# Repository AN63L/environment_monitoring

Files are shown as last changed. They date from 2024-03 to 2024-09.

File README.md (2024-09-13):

# Environment monitoring system and simple web server
Budget friendly and lower-power consumption environment monitoring system with ESP32 board, BME680 sensor and PM-G7.

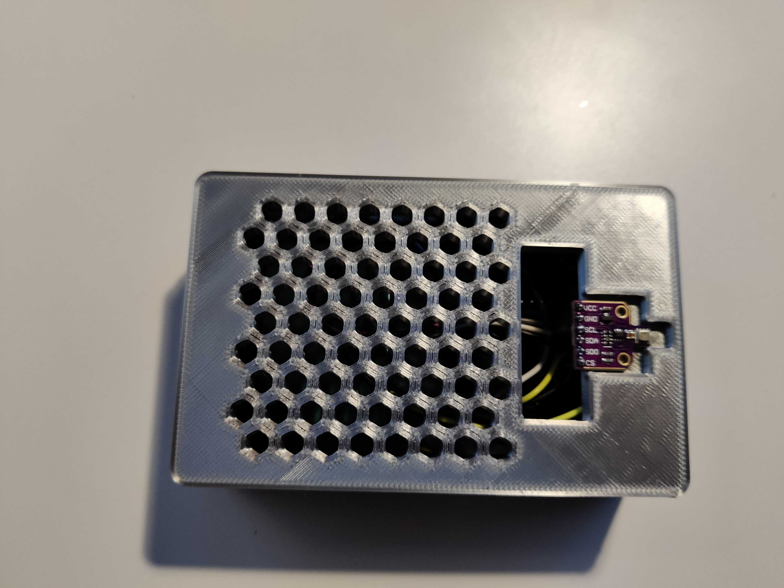
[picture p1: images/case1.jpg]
Case view

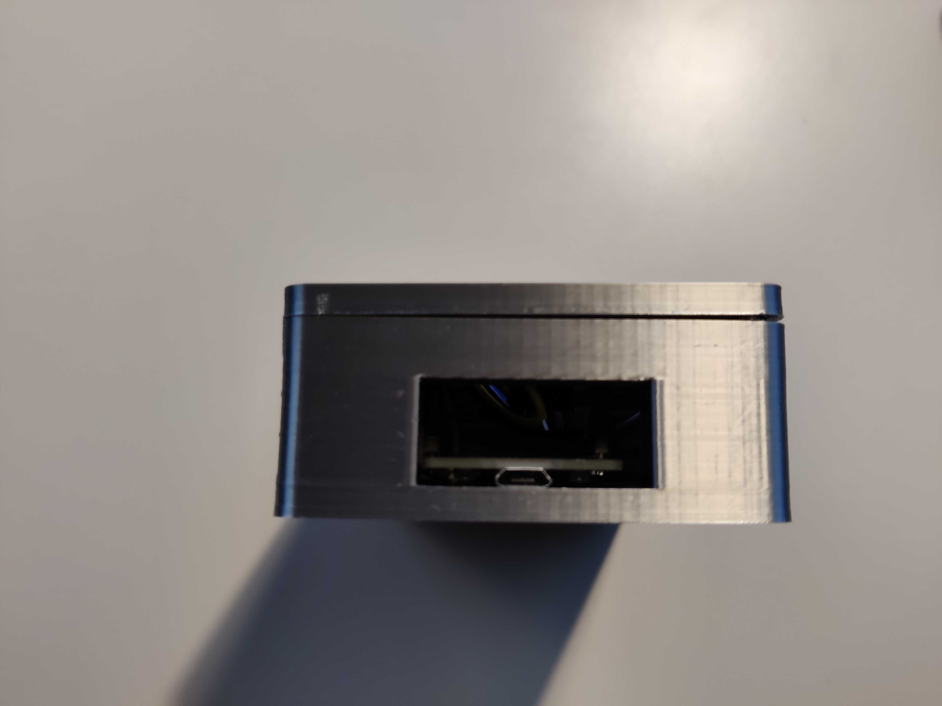
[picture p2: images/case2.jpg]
Case view

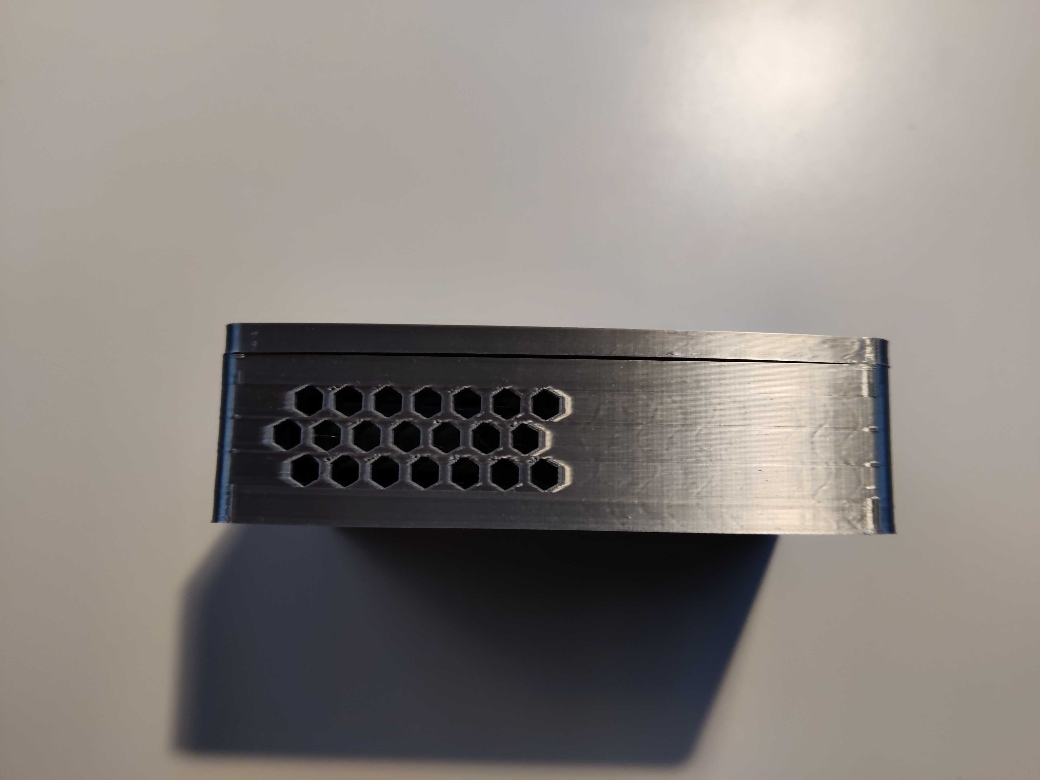
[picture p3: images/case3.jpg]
Case view

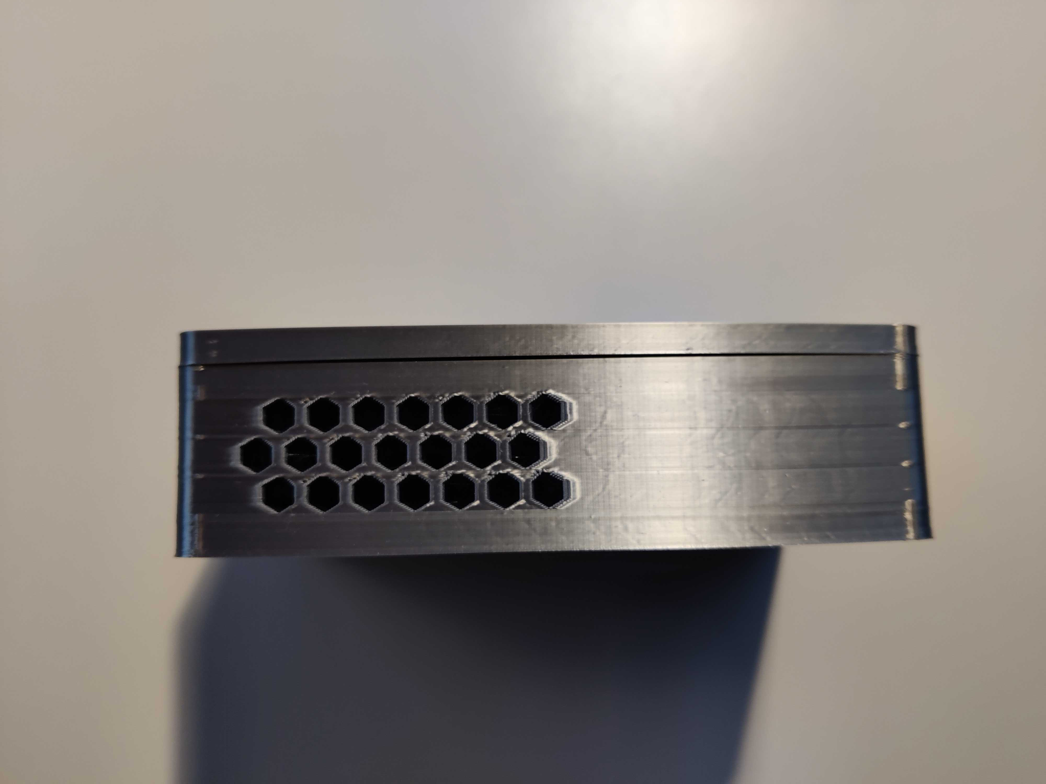
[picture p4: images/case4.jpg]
Case view


## Overview

This guide is part of a project I built to monitor the air quality, temperature, humidity, pressure and gas in a closed room. 

It's built using an ESP32 board for its low power consumption and small size. 

I've paired this project with a notification system (only for HA), you can configure different notifications based on my needs. It's placed in a room and notifies me when: 
- The air quality has deteriorated and I need to open a window to refresh the air
- The temperature is running high and I need to cool down with a fan
- The temperature is running low and I need to turn up the heaters
- The air quality is dangerous because of different levels of gas
- The air quality based on the PMS sensor data

I've also 3D printed a small case (PLA) to hold the pieces together.

Excluding time for build and development, the breakdown of the costs are as follows: 

- EUR 7.66 for the ESP32
- EUR 18.50 for the BME680 sensor
- EUR 19.99 for the PMS7003 sensor
- EUR 1.95 PMS7003 sensor adapter
- EUR 0.67 for the 8 magnets
- EUR 5 for the power supply (I used a micro-USB power supply I had already, I'm guessing you can get one for that price off Amazon)
- EUR 20 for the soldering iron
- EUR 0.69 for the 69 grams of PLA (approx)
- 
The total of this project comes down to round **EUR 80**.

I used platformIO to manage the ESP32, the main folder with the content is available in the folder "ESP32 ENVIRONMENT MONITORING SYSTEM"

## Resources

- [ESP32 board by diymore ](https://www.amazon.fr/dp/B0BS6R68H6?psc=1&ref=ppx_yo2ov_dt_b_product_details)
- [BME680 sensor](https://www.amazon.fr/dp/B07K1CGQTJ?psc=1&ref=ppx_yo2ov_dt_b_product_details)
- [PM-G7 / PMSA7003 sensor](https://www.amazon.fr/dp/B0B1526JHQ?psc=1&ref=ppx_yo2ov_dt_b_product_details)
- [PMS7003 sensor adapter](https://soldered.com/product/pms7003-sensor-adapter/)
- 8 Jumper cables (female to female)
- PLA + (I have a personal preference for SUNLU PLA +, but you can use any kind of PLA)
- [5x3mm magnets for the case](https://www.amazon.fr/dp/B0C9WQYZ27?ref=ppx_yo2ov_dt_b_product_details&th=1)
- A soldering iron and relevant materials
- Superglue to glue the BME680 sensor to the case

## 3D prints

The parts were printed using a Creality CR-20 pro. 

The pieces are as follows: 
- Lid (v3) 
- Case (v2) (or case_soldered)

The original version of the case had some issues: 
- there was not enough space to attach the jumper cables to the BME680 sensor
- the stands for the ESP32 were way too far (the reference model I used was incorrect) and the stand weren't solid enough
- the whole for the charging port of the ESP32 was a little too low
- the depth of the magnets could be improved by 1mm to avoid any space between the lid and the case

Overall it should work if you print it but you'll need to find a way to connect the BME680 sensor, remove the stands. You could glue everything together with hot glue to avoid any issues with the charging port of the ESP32. 

I wanted to improve the design in general and fix the above issues, you'll find the second version of the case is much better overall. 

There are three versions of the lid. For some reason, I could not print the first version with the hex holes, so I created the second version which should provide a lot more air to the sensors but is less beautiful and is not suitable for exterior use. 

The third version is cleaned up to fit my needs with enough air, with a better design, rounded corners and a thinner format.

The print times totals to 8h and 34 minutes. 

*If you are using the soldered adapter* I made improvements to the case, as the previous versions didn't leave enough space for the jumper cables (see image below). I took the opportunity to remove the space for the PMS7003 which wasn't fit for purpose (see comment above).

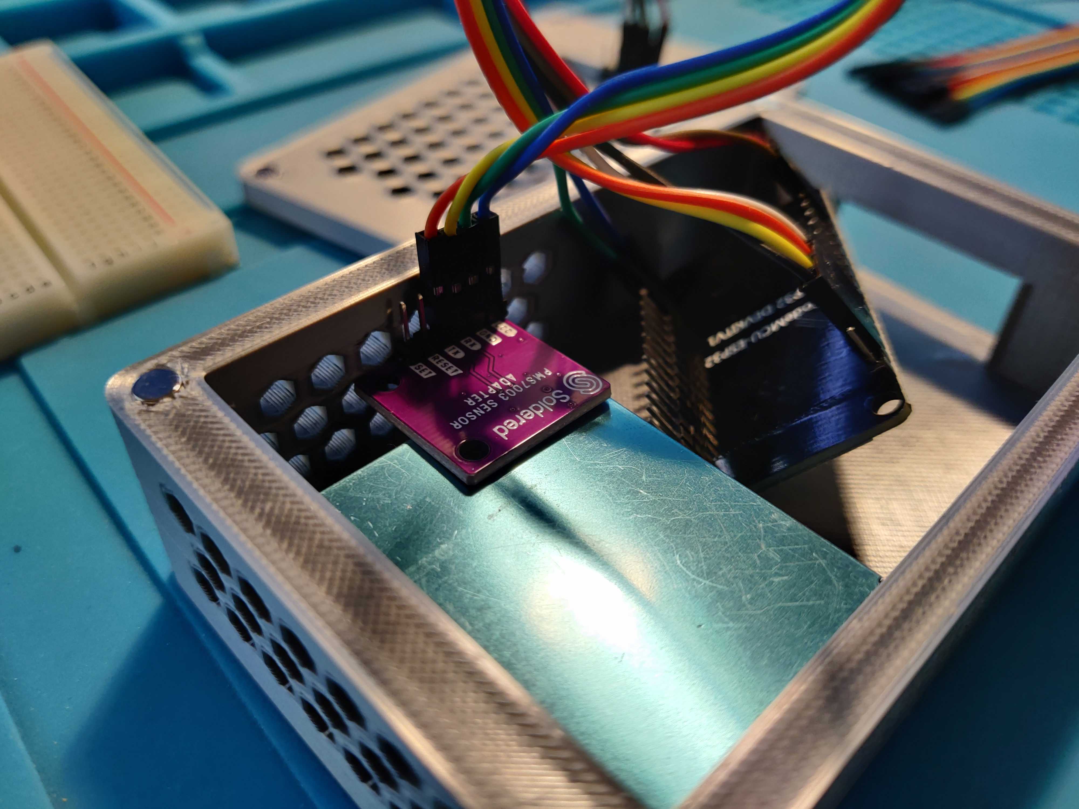
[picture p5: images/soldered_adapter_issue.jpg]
Soldered adapter issue


You'll have to flip the lid 180 degrees, with the holes facing outward. This will make it easier to remove the supports for the BME680 sensor holder rather than the holes. 

My slicer settings were as follows: 

- Infill: 10%
- Infill pattern: Gyroid
- Support: Touching build plate
- Support pattern: lines
- Nozzle size: 0.4mm
- Nozzle temp: 210 degrees
- Bed temp: 60 degrees
- Print speed: 80 mm/s
- Infill speed" 40 mm/s
- Travel speed 200 mm/s
- Initial layer speed: 20 mm/s
- Support: everywhere at 80 degrees angle
- **Remove overlapping volumes in Mesh fixes settings in order to print honeycomb holes on lid**

## Assembly and wiring

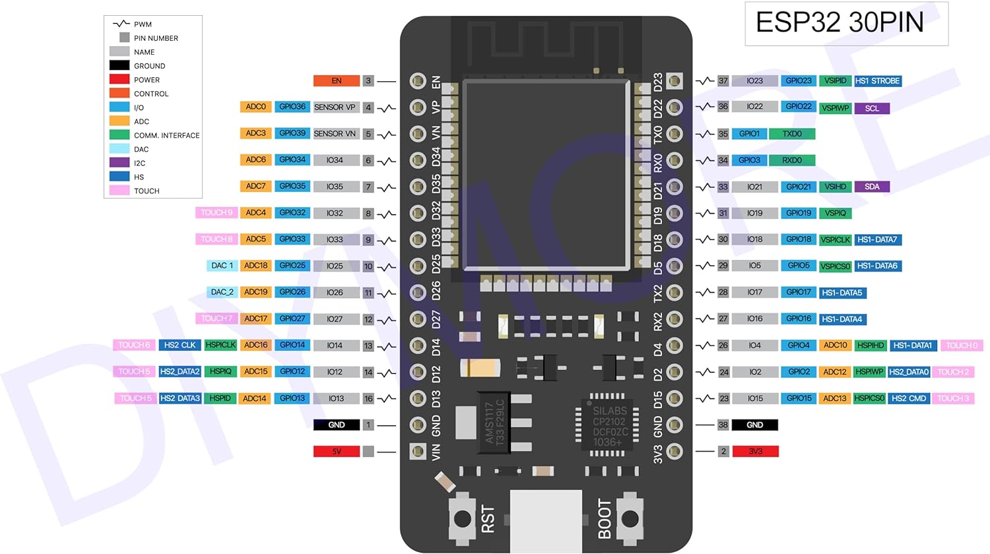
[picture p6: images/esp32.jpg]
ESP32 pin-out for reference


1. First, solder the pins to the BME680 if they weren't soldered together in the first place. I used a breadboard and jumper cable to keep it aligned during the soldering. 
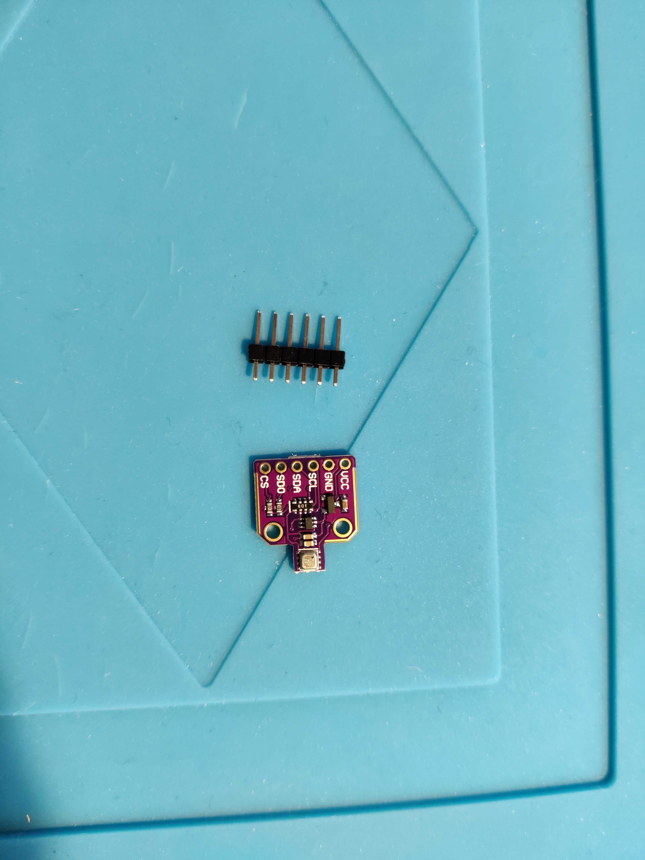
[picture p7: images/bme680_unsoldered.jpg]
BME680 unsoldered

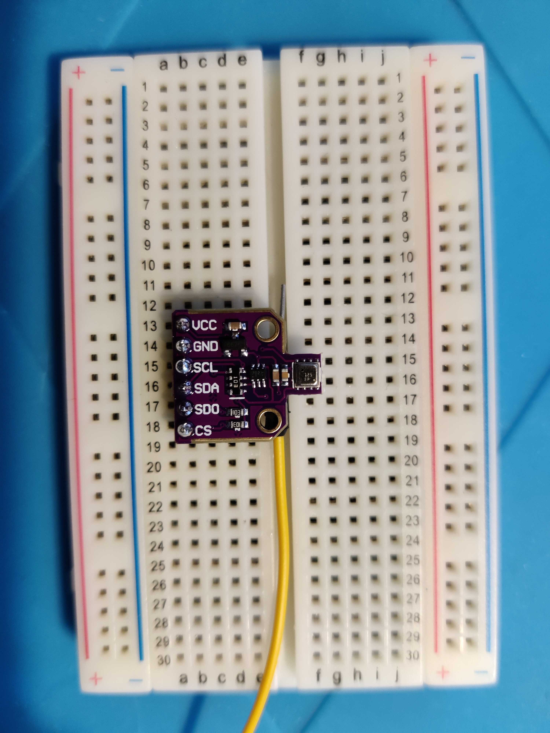
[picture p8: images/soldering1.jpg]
Soldering 1

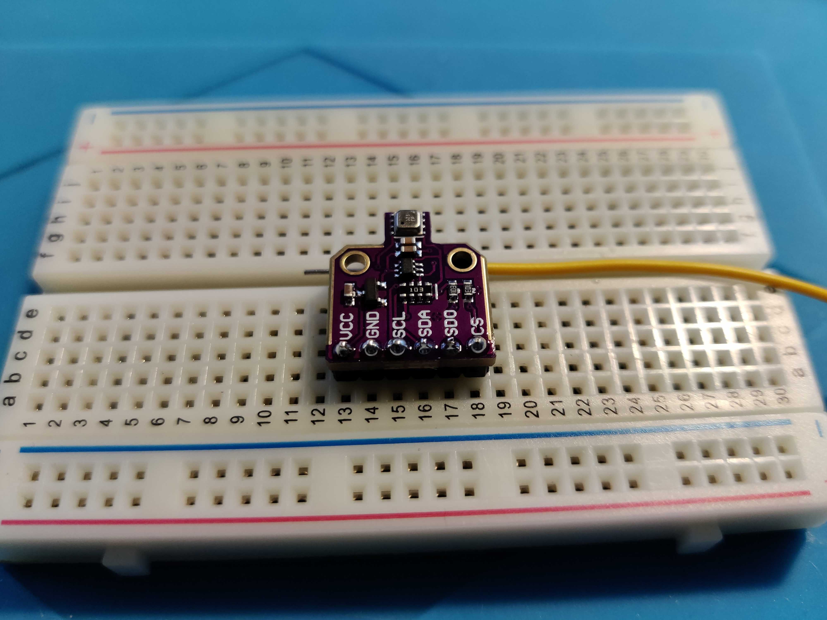
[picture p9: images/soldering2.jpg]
Soldering 2


2. Next we wire the BME680 sensor to the ESP32, using the I2C connection
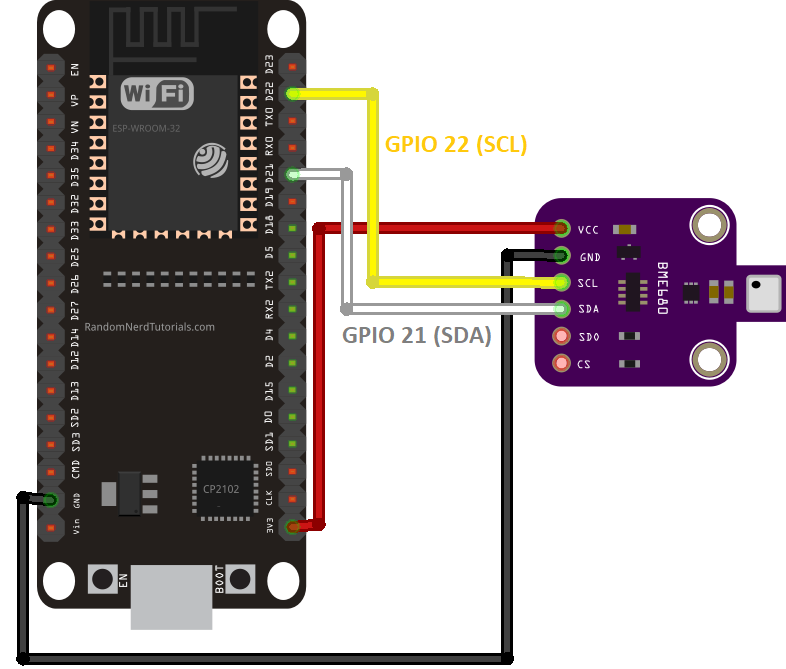
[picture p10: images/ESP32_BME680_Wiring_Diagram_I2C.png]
BME TO ESP32 SPI


Optionally, you can use the SPI connection (however it won't work with home assistant add-on, I2C is required).

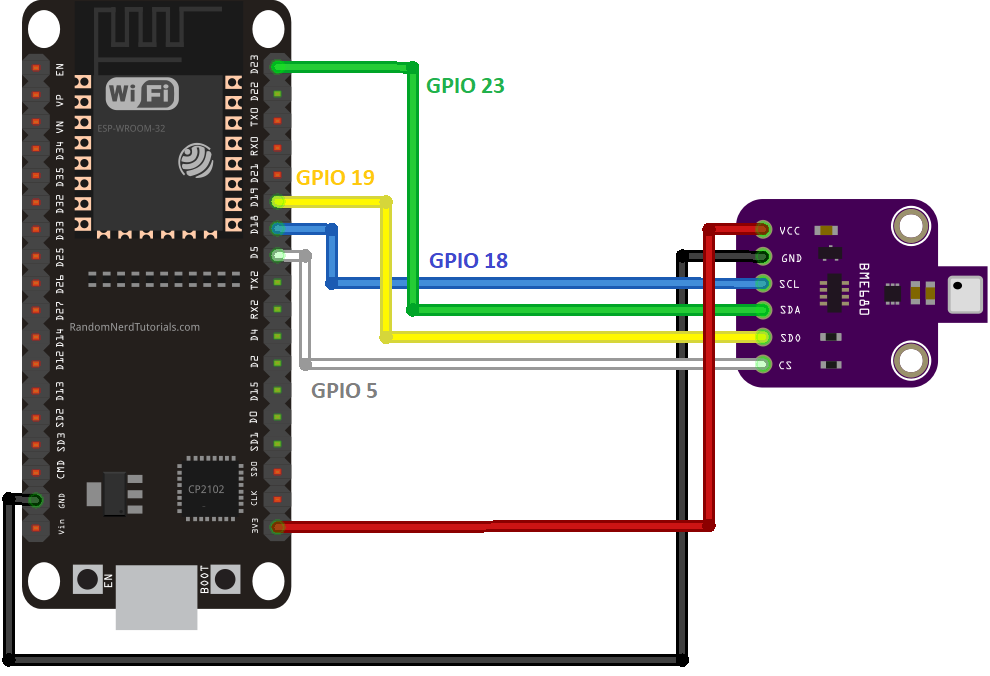
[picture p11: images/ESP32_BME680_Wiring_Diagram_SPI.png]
BME TO ESP32 I2C


3. Next we will connect the PMS7003. If you are lucky, you go one with an adaptor board to make the assembly. I originally didn't and had to solder the pins myself (bad idea). After buying an adapter, I followed the connections below. The connection are pretty self explanatory.

For HA: <br />
RX -> TX0 <br />
TX -> RX0 <br />
For the version of the software without HA:<br />
RX -> TX2 <br />
TX -> RX2 <br />
VCC -> VIN <br />
GND -> GND <br />

4. Install the magnets in place. The holes might seem a little too tight but if you slowly push in the magnets they will fit perfectly into place (using a flat surface like a hammer helps). Make sure the polarity is correct (you want to close the lid on the case!)

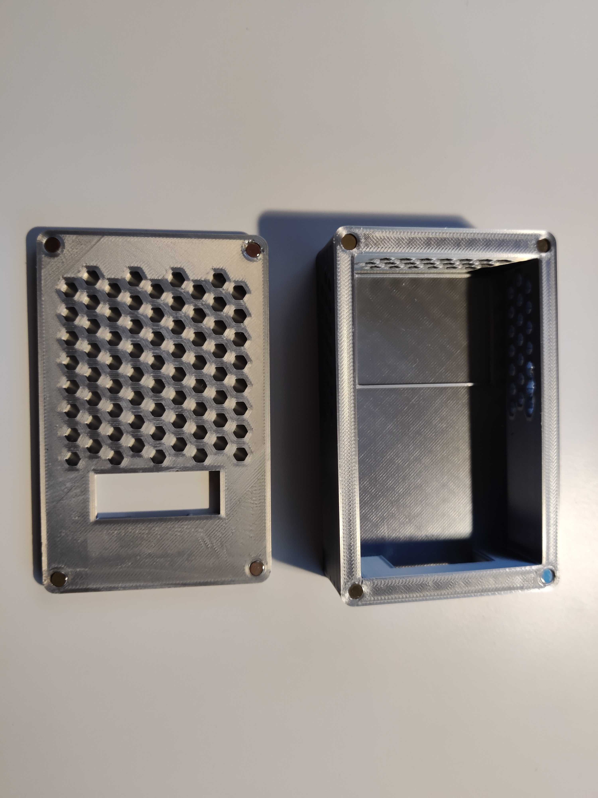
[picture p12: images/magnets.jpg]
Magnets placed inside case


5. Glue the BME680 sensor to the case (base of the component)

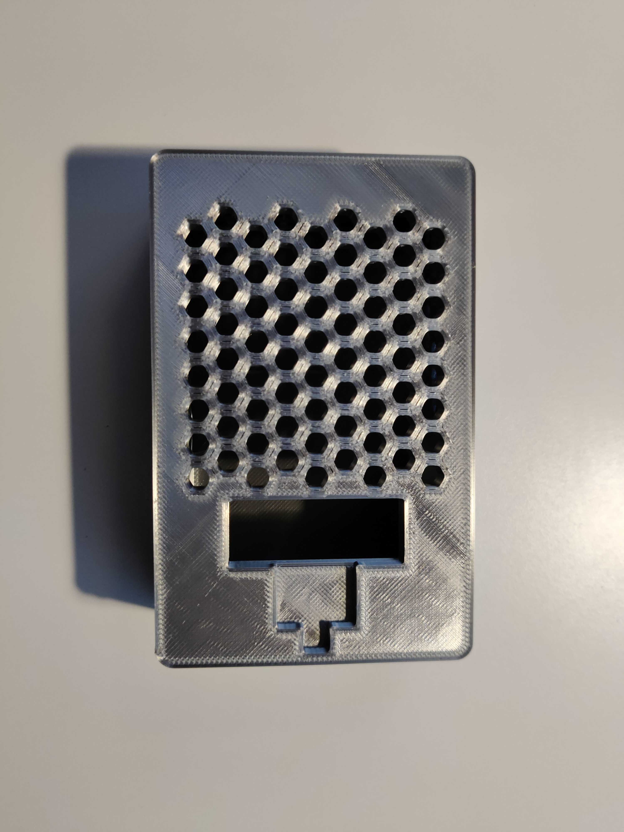
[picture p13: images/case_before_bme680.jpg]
Without BME680 sensor

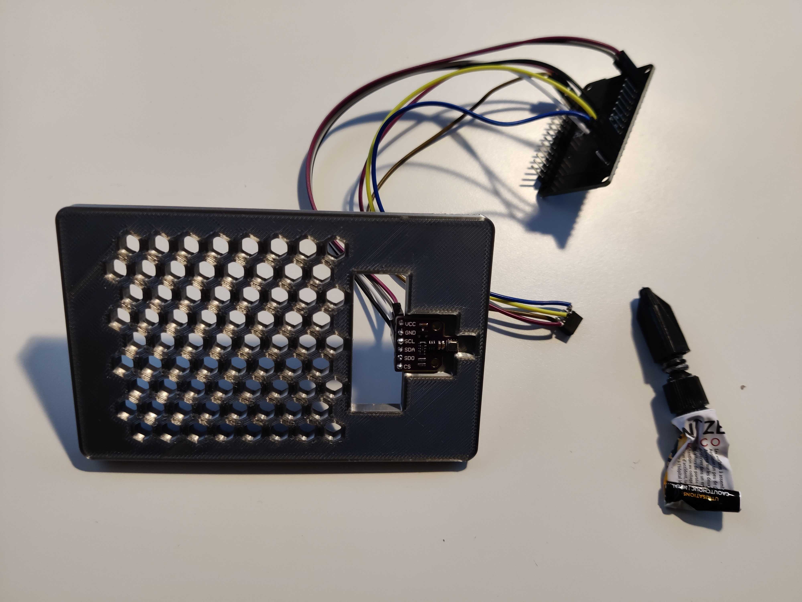
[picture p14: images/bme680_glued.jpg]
BME680 glued sensor


6. Place the components inside

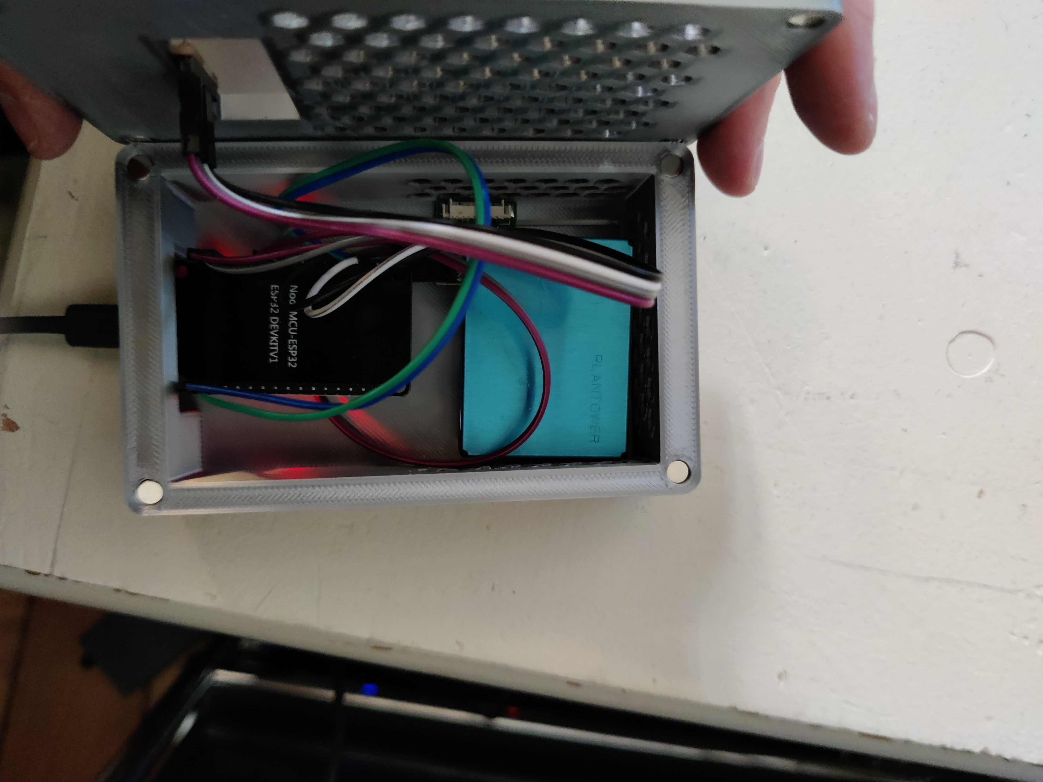
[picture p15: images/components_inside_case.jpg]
Components inside case


7. (optional) glue with hot glue the ESP32 in place (depending on the length of your jumper cables it might not be an issue but because there is no holder you'll have to open the lid every time you plug/unplug the ESP32)

8. close the lid and you're ready to go !

## Software setup

I'm assuming you are familiar with the ESP32 micro-controller and now how to access and run it. There are loads of guides to get started, you can use these for reference: 
- https://randomnerdtutorials.com/getting-started-with-esp32/
- https://www.youtube.com/watch?v=tc3Qnf79Ny8

- Setup a new project using PlatformIO
- Install the ESP32 Boardard Adafruit BME680 Library (The latest version I installed was 2.0.4)
- Install the PMserial library by Alvaro Valdebenito (the latest version I installed was 1.2.0)
- Install ESPAsyncWebServer-esphome library (the latest version I installed was 2.1.0)
- Install the AsyncTCP-esphome library (the latest version I installed was 1.2.2)
- Upload the code using platformIO. If your board is like mine, **press boot when the terminal shows "connecting...."**

*Notes*:
- Don't forget to specify `build_flags = -D PMS_RX=16 -D PMS_TX=17` in platformio.ini or your execution will fail and you will get an error during BME680 initialisation (although these flags are required for the PMS7003)
- Plugging the PMS7003 on the RX0 and TX0 pins results in errors entering the bootloader and makes updated impossible.

## Software explanations

I've included comments inside the code for additional explanations. You can un-comment certain lines to enable console logging.

The code does the following on a loop: 

1. Initialise the pins
2. Initialise the sensors (BME680 and PMS7003)
3. Initialise the server
4. Turn on the LED
5. Gather the data through the BME680 sensor
6. Update the global values
7. Display the values on the web page
8. Turn the LED off
9. Sleep

The `setup()` function initialises the BME680, server with the STA connection, sampling for the sensor and pin for the LED.

The `loop()` function handles the led on/off, BME680 readings and sending the sensor data back to the server. 

The `processor()` function handles the update of the variables inside the `index_html` variable.

The `notFound()` function simply sends a 404 response if the page is not found.

## Usage

To connect to the server, simply visit inside a web browser the IP of the ESP32 (displayed inside the serial console).

## Environment variable handling

https://stackoverflow.com/questions/62314497/access-of-outer-environment-variable-in-platformio

### Bonus: ESPHome for HomeAssistant (only for the first configuration)

Using ESPHome will not work in combination with the code provided. Any actions you take will remove any work done through platformIO.

Installing ESPHome will remove the need for the code provided and the use of PlatformIO. You will have access to the sensors directly from HA. 

I followed [this guide](https://www.youtube.com/watch?v=7PoUWszwaFk) to setup ESPHome on the ESP32. 

The official ESPHome page is available [here](https://esphome.io/guides/getting_started_hassio).

I'm assuming you already have Home Assistant installed. 

1. Make sure you are running the latest version of Home Assistant Core and Home Assistant OS, upgrade if necessary. I am running version 2024.3.1 of HA Core and version 12.1 of HA OS. 
2. Install ESPHome add-on with all the toggles activated (hopefully you have Home Assistant OS and not a docker install, it's much easier - just click the "Show Add-on on My" to install the add-on)
3. Install ESPHome on the ESP32, a useful guide can be found [here](https://www.youtube.com/watch?v=mCs0fa7Gr9U) or [this one](https://www.youtube.com/watch?v=7PoUWszwaFk). I used "OpenESPHomeWeb" to install ESPHome on the ESP32 board (this was the easiest method I found)
4. Add this [BME680 add-on](https://esphome.io/components/sensor/bme680) to your ESP32 configuration:
   ```
    i2c: 
        # Example configuration entry
        sensor:
        - platform: bme680
            temperature:
            name: "BME680 Temperature"
            oversampling: 16x
            pressure:
            name: "BME680 Pressure"
            humidity:
            id: "humidity"
            name: "BME680 Humidity"
            gas_resistance:
            id: "gas_resistance"
            name: "BME680 Gas Resistance"
            address: 0x77
            update_interval: 30s
        - platform: template
            name: "BME680 Indoor Air Quality"
            id: iaq
            icon: "mdi:gauge"
            # calculation: comp_gas = log(R_gas[ohm]) + 0.04 log(Ohm)/%rh * hum[%rh]
            lambda: |-
            return log(id(gas_resistance).state) + 0.04 *  id(humidity).state;
        text_sensor:
        - platform: template
            name: "BME680 IAQ Classification"
            icon: "mdi:checkbox-marked-circle-outline"
            lambda: |-
            if (int(id(iaq).state) <= 50) {
                return {"Excellent"};
            }
            else if (int(id(iaq).state) <= 100) {
                return {"Good"};
            }
            else if (int(id(iaq).state) <= 150) {
                return {"Lightly polluted"};
            }
            else if (int(id(iaq).state) <= 200) {
                return {"Moderately polluted"};
            }
            else if (int(id(iaq).state) <= 250) {
                return {"Heavily polluted"};
            }
            else if (int(id(iaq).state) <= 350) {
                return {"Severely polluted"};
            }
            else if (int(id(iaq).state) <= 500) {
                return {"Extremely polluted"};
            }
            else {
                return {"unknown"};
            }
   ```
5. Add this [PMSX003 add-on](https://esphome.io/components/sensor/pmsx003) to your ESP32 configuration

Before the i2c variable: 

```
uart:
  rx_pin: RX
  tx_pin: TX
  baud_rate: 9600
```

You cannot have two "sensor" variables, please add another sensor element: 

```
sensor:
  - platform: pmsx003
    type: PMSX003
    pm_1_0:
      name: "Particulate Matter <1.0µm Concentration"
    pm_2_5:
      name: "Particulate Matter <2.5µm Concentration"
    pm_10_0:
      name: "Particulate Matter <10.0µm Concentration"
    update_interval: 30s
```

The final result should look something like this: 

```
substitutions:
  name: esphome-web-f34cc0
  friendly_name: ESP32 Environment Sensors

esphome:
  name: ${name}
  friendly_name: ${friendly_name}
  name_add_mac_suffix: false
  project:
    name: esphome.web
    version: '1.0'

esp32:
  board: esp32dev
  framework:
    type: arduino

# Enable logging
logger:

# Enable Home Assistant API
api:

# Allow Over-The-Air updates
ota:

# Allow provisioning Wi-Fi via serial
improv_serial:

wifi:
  # Set up a wifi access point
  ap: {}

# In combination with the `ap` this allows the user
# to provision wifi credentials to the device via WiFi AP.
captive_portal:

dashboard_import:
  package_import_url: github://esphome/example-configs/esphome-web/esp32.yaml@main
  import_full_config: true

# Sets up Bluetooth LE (Only on ESP32) to allow the user
# to provision wifi credentials to the device.
esp32_improv:
  authorizer: none

# To have a "next url" for improv serial
web_server:

uart:
  rx_pin: RX
  tx_pin: TX
  baud_rate: 9600

i2c:
  # Example configuration entry
sensor:
  - platform: bme680
    temperature:
      name: "BME680 Temperature"
      oversampling: 16x
    pressure:
      name: "BME680 Pressure"
    humidity:
      id: "humidity"
      name: "BME680 Humidity"
    gas_resistance:
      id: "gas_resistance"
      name: "BME680 Gas Resistance"
    address: 0x77
    update_interval: 30s
  - platform: template
    name: "BME680 Indoor Air Quality"
    id: iaq
    icon: "mdi:gauge"
    # caulculation: comp_gas = log(R_gas[ohm]) + 0.04 log(Ohm)/%rh * hum[%rh]
    lambda: |-
      return log(id(gas_resistance).state) + 0.04 *  id(humidity).state;
  - platform: pmsx003
    type: PMSX003
    pm_1_0:
      name: "Particulate Matter <1.0µm Concentration"
    pm_2_5:
      name: "Particulate Matter <2.5µm Concentration"
    pm_10_0:
      name: "Particulate Matter <10.0µm Concentration"
    update_interval: 120s
text_sensor:
  - platform: template
    name: "BME680 IAQ Classification"
    icon: "mdi:checkbox-marked-circle-outline"
    lambda: |-
      if (int(id(iaq).state) <= 50) {
        return {"Excellent"};
      }
      else if (int(id(iaq).state) <= 100) {
        return {"Good"};
      }
      else if (int(id(iaq).state) <= 150) {
        return {"Lightly polluted"};
      }
      else if (int(id(iaq).state) <= 200) {
        return {"Moderately polluted"};
      }
      else if (int(id(iaq).state) <= 250) {
        return {"Heavily polluted"};
      }
      else if (int(id(iaq).state) <= 350) {
        return {"Severely polluted"};
      }
      else if (int(id(iaq).state) <= 500) {
        return {"Extremely polluted"};
      }
      else {
        return {"unknown"};
      }
```

1. (optional) Add automations in home assistant to send notifications

And you're done! You should be able to add the sensor information to your dashboard. Refer to the documentation for additional configuration.

## Final comments

I used different online guides to get to the final results. You'll find some references below.

- [BME Sensor SPI setup](https://randomnerdtutorials.com/esp32-bme680-sensor-arduino/)
- https://www.pieterbrinkman.com/2021/02/03/build-a-cheap-air-quality-meter-using-esphome-home-assistant-and-a-particulate-matter-sensor/

## Future improvements

- Add a placeholder for the ESP32, for the moment it has no holder. It's not moving much because of the length of the cables but it is not ideal. 
- I badly designed the holder for the PMS7003, assuming the breakout board would with inside but unfortunately the design needs to be improved to take account of the extra space needed.
- The size of the space for the pins of the BME680 is quite large and the placeholder for the BME680 as well. I built it as such so that you can also use other kinds of sensors (I'm planning on adding a soil sensor and humidity sensor), leaving enough space for jumper cables to go out of the case.
- Make it more portable by using a portable battery
- I would have liked to add an OLED display but was limited by the number of power GPIOs (an extension board is needed)

## Guides 

- https://randomnerdtutorials.com/esp32-bme680-sensor-arduino/
- https://github.com/avaldebe/PMserial
- https://www.espruino.com/PMS7003
- https://hpclab.blogspot.com/2020/02/esp8266-based-wifi-air-quality.html
- https://learn.adafruit.com/pm25-air-quality-sensor?view=all
- https://esphome.io/components/sensor/bme680
- https://esphome.io/components/sensor/pmsx003
- https://stackoverflow.com/questions/62314497/access-of-outer-environment-variable-in-platformio

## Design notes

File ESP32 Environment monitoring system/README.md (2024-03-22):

# Environment monitoring system with notification system
Budget friendly and lower-power consumption environment monitoring system with ESP32 board, BME680 sensor and PM-G7.

## Overview

This guide is part of a project I built to monitor the air quality, temperature, humidity, pressure and gas in a closed room. 

It's built using an ESP32 board for its low power consumption and small size. 

I've paired this project with a notification system, you can configure different notifications based on my needs. It's placed in a room and notifies me when: 
- The air quality has deteriorated and I need to open a window to refresh the air
- The temperature is running high and I need to cool down with a fan
- The temperature is running low and I need to turn up the heaters
- The air quality is dangerous because of different levels of gas

I've also 3D printed a small case (PLA) to hold the pieces together.

Excluding time for build and development, the breakdown of the costs are as follows: 

- EUR 7.66 for the ESP32
- EUR 18.50 for the BME680 sensor
- EUR 19.99 for the PMS7003 sensor
- EUR 0.67 for the 8 magnets
- EUR 5 for the power supply (I used a micro-USB power supply I had already, I'm guessing you can get one for that price off Amazon)
- EUR 20 for the soldering iron
- EUR for the X grams of PLA
- EUR for the X kilowatts of energy to print the piece (X hours)

The total of this project comes down to round **EUR 80**

I used platformIO to manage the ESP32, the main folder with the content is available in the folder "ESP32 ENVIRONMENT MONITORING SYSTEM"

## Resources

- [ESP32 board by diymore ](https://www.amazon.fr/dp/B0BS6R68H6?psc=1&ref=ppx_yo2ov_dt_b_product_details)
- [BME680 sensor](https://www.amazon.fr/dp/B07K1CGQTJ?psc=1&ref=ppx_yo2ov_dt_b_product_details)
- [PM-G7 sensor](https://www.amazon.fr/dp/B0B1526JHQ?psc=1&ref=ppx_yo2ov_dt_b_product_details)
- X Jumper cables (female to female)
- PLA + (I have a personal preference for SUNLU PLA +, but you can use any kind of PLA)
- [5x3mm magnets for the case](https://www.amazon.fr/dp/B0C9WQYZ27?ref=ppx_yo2ov_dt_b_product_details&th=1)
- Some strong glue to stick the magnets to the case
- A soldering iron and relevant materials

## 3D prints

The parts were printed using a Creality CR-20 pro. 

The pieces are as follows: 

The print times are as follows: 

My slicer settings were as follows: 

## Assembly and wiring

ESP32 pin-out for reference

1. First, solder the pins to the BME680 if they weren't soldered together in the first place. I used a breadboard and jumper cable to keep it aligned during the soldering. 
BME680 unsoldered
Soldering 1
Soldering 2

2. Next we wire the BME680 sensor to the ESP32, using the I2C connection
BME TO ESP32 SPI

Optionally, you can use the SPI connection (however it won't work with home assistant add-on, I2C is required).

BME TO ESP32 I2C

3. Next we will connect the PMS7003. If you are lucky, you go one with an adaptor board to make the assembly. I didn't and had to solder the pins myself. The connections are shown below.

PMS7003 Front
PMS7003 Back

Beware: the pins are very fragile and close together, I highly recommend you use an adapter board instead.

## Software setup

I'm assuming you are familiar with the ESP32 micro-controller and now how to access and run it. There are loads of guides to get started, you can use these for reference: 
- https://randomnerdtutorials.com/getting-started-with-esp32/
- https://www.youtube.com/watch?v=tc3Qnf79Ny8

- Setup a new project using PlatformIO
- Install the ESP32 Boardard Adafruit BME680 Library (The latest version I installed was 2.0.4)
- Install the PMserial library by Alvaro Valdebenito (the latest version I installed was 1.2.0)
- Upload the code using platformIO. If your board is like mine, **press boot when the terminal shows "connecting...."**

## Software explanations

I've included comments inside the code for additional explanations.

The code does the following on a loop: 

1. Initialise the pins
2. Turn on the LED
3. Gather the data through the BME680 sensor
4. Turn the LED off
5. Sleep

### Bonus: ESPHome for HomeAssistant

Using ESPHome will not work in combination with the code provided. Any actions you take will remove any work done through platformIO.

Installing ESPHome will remove the need for the code provided and the use of PlatformIO. You will have access to the sensors directly from HA. 

I followed [this guide](https://www.youtube.com/watch?v=7PoUWszwaFk) to setup ESPHome on the ESP32. 

The official ESPHome page is available [here](https://esphome.io/guides/getting_started_hassio).

I'm assuming you already have Home Assistant installed. 

1. Make sure you are running the latest version of Home Assistant Core and Home Assistant OS, upgrade if necessary. I am running version XX of HA Core and version XXX of HA OS. 
2. Install ESPHome add-on with all the toggles activated (hopefully you have Home Assistant OS and not a docker install, it's much easier - just click the "Show Add-on on My" to install the add-on)
3. Install ESPHome on the ESP32, a useful guide can be found [here](https://www.youtube.com/watch?v=mCs0fa7Gr9U) or [this one](https://www.youtube.com/watch?v=7PoUWszwaFk). I used "OpenESPHomeWeb" to install ESPHome on the ESP32 board (this was the easiest method I found)
4. Add this [BME680 add-on](https://esphome.io/components/sensor/bme680) to your ESP32 configuration:
   ```
    i2c: 
        # Example configuration entry
        sensor:
        - platform: bme680
            temperature:
            name: "BME680 Temperature"
            oversampling: 16x
            pressure:
            name: "BME680 Pressure"
            humidity:
            id: "humidity"
            name: "BME680 Humidity"
            gas_resistance:
            id: "gas_resistance"
            name: "BME680 Gas Resistance"
            address: 0x77
            update_interval: 30s
        - platform: template
            name: "BME680 Indoor Air Quality"
            id: iaq
            icon: "mdi:gauge"
            # calculation: comp_gas = log(R_gas[ohm]) + 0.04 log(Ohm)/%rh * hum[%rh]
            lambda: |-
            return log(id(gas_resistance).state) + 0.04 *  id(humidity).state;
        text_sensor:
        - platform: template
            name: "BME680 IAQ Classification"
            icon: "mdi:checkbox-marked-circle-outline"
            lambda: |-
            if (int(id(iaq).state) <= 50) {
                return {"Excellent"};
            }
            else if (int(id(iaq).state) <= 100) {
                return {"Good"};
            }
            else if (int(id(iaq).state) <= 150) {
                return {"Lightly polluted"};
            }
            else if (int(id(iaq).state) <= 200) {
                return {"Moderately polluted"};
            }
            else if (int(id(iaq).state) <= 250) {
                return {"Heavily polluted"};
            }
            else if (int(id(iaq).state) <= 350) {
                return {"Severely polluted"};
            }
            else if (int(id(iaq).state) <= 500) {
                return {"Extremely polluted"};
            }
            else {
                return {"unknown"};
            }
   ```
5. Add this [PMSX003 add-on](https://esphome.io/components/sensor/pmsx003) to your ESP32 configuration

Before the i2c variable: 

```
uart:
  rx_pin: GPIO3
  tx_pin: GPIO1
  baud_rate: 9600
```

You cannot have two "sensor" variables, please add another sensor element: 

```
sensor:
  - platform: pmsx003
    type: PMSX003
    pm_1_0:
      name: "Particulate Matter <1.0µm Concentration"
    pm_2_5:
      name: "Particulate Matter <2.5µm Concentration"
    pm_10_0:
      name: "Particulate Matter <10.0µm Concentration"
    update_interval: 30s
```

The final result should look something like this: 

```
XXX
```

1. (optional) Add automations in home assistant to send notifications

And you're done! You should be able to add the sensor information to your dashboard. Refer to the documentation for additional configuration.

## Final comments

I used different online guides to get to the final results. You'll find some references below.

- [BME Sensor SPI setup](https://randomnerdtutorials.com/esp32-bme680-sensor-arduino/)
- https://www.pieterbrinkman.com/2021/02/03/build-a-cheap-air-quality-meter-using-esphome-home-assistant-and-a-particulate-matter-sensor/

## Future improvements

- Improve the connections with the PMS7003 sensor by using an adapter board, it would make the connections less fragile and easier to setup
- Make it more portable by using a portable battery
- I would have liked to add an OLED display but was limited by the number of power GPIOs
- A server can be added to display the results on a web page and additional notifications

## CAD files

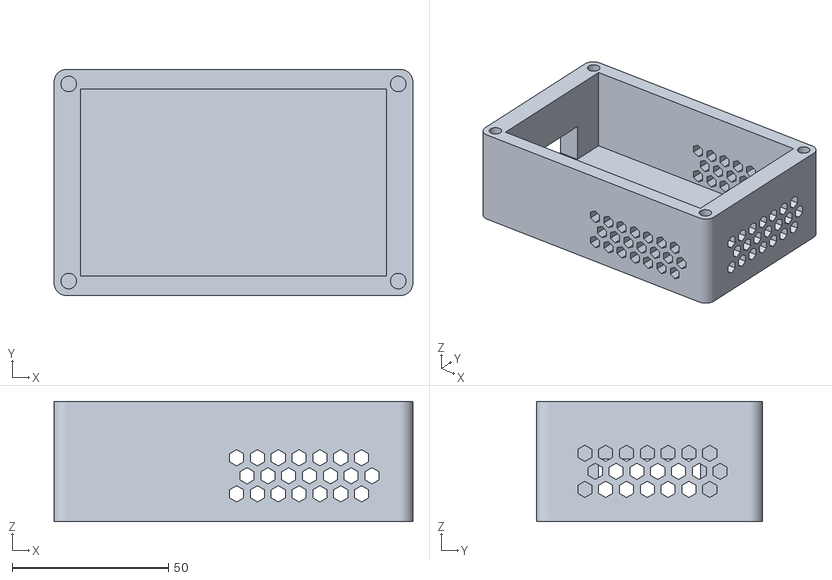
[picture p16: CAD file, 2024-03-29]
stl/case_soldered.stl
115.0 x 72.5 x 38.5

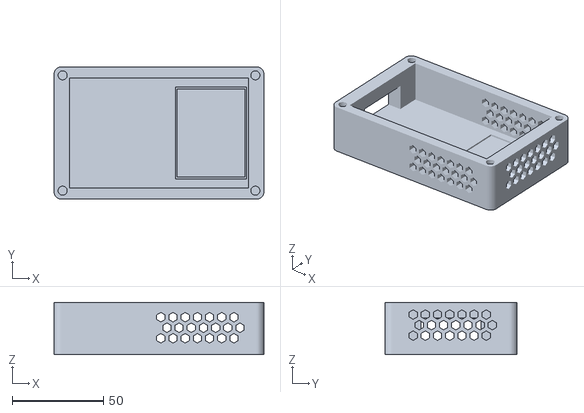
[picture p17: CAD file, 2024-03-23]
stl/case_v2.stl
115.0 x 72.5 x 28.5

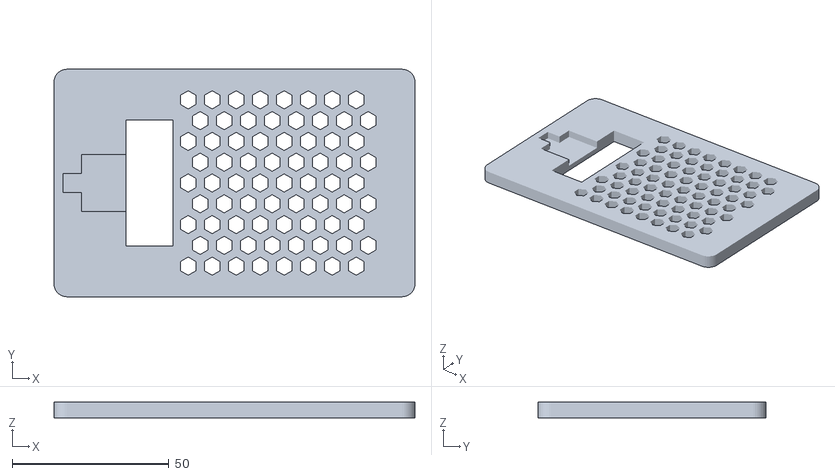
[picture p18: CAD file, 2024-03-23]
stl/lid_v3.stl
115.0 x 72.5 x 5.00

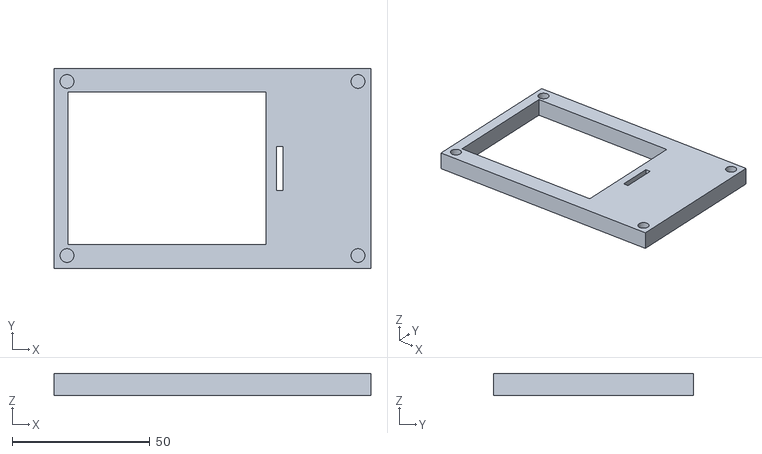
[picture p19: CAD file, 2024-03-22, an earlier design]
stl/archives/lid_v2.stl
115.0 x 72.5 x 8.00

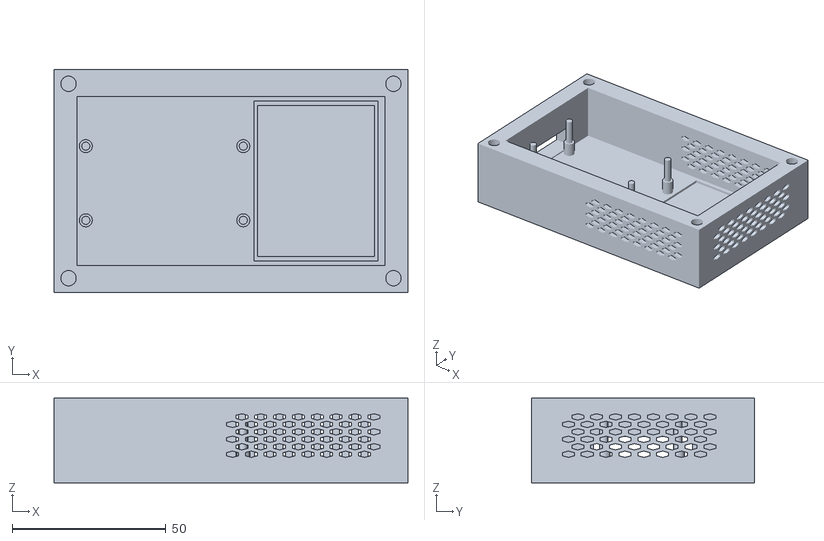
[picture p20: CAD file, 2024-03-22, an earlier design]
stl/archives/case.stl
115.0 x 72.5 x 27.6

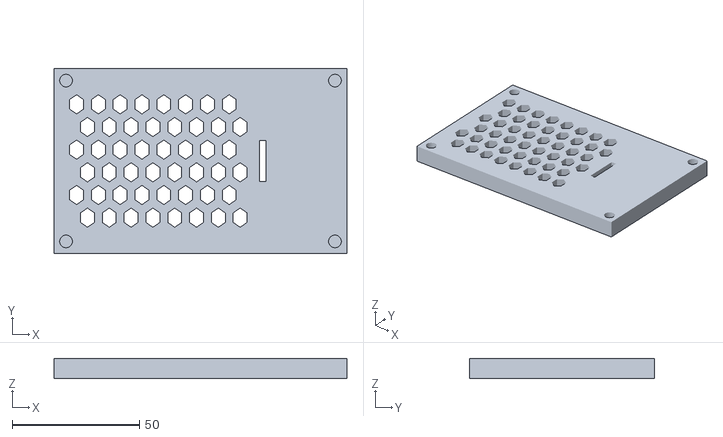
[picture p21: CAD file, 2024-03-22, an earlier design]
stl/archives/lid.stl
115.0 x 72.5 x 8.00

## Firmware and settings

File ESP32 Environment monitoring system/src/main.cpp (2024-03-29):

// For BME680
#include <Wire.h>
#include <Adafruit_Sensor.h>
#include "Adafruit_BME680.h"
#define SEALEVELPRESSURE_HPA (1013.25)
Adafruit_BME680 bme; // I2C
// For SPI
// #define BME_SCK 18
// #define BME_MISO 19
// #define BME_MOSI 23
// #define BME_CS 5
// Adafruit_BME680 bme(BME_CS, BME_MOSI, BME_MISO, BME_SCK);

// FOR PMS
#include <PMserial.h>
SerialPM pms(PMSx003, PMS_RX, PMS_TX); // PMSx003, RX, TX

// for onboard LED
#define LED 2

// For server
#include <WiFi.h>
#include "AsyncTCP.h"
#include "ESPAsyncWebServer.h"

// Creds for WiFi
// https://stackoverflow.com/questions/62314497/access-of-outer-environment-variable-in-platformio
#define XSTR(x) #x
#define STR(x) XSTR(x)
const char *wifi_ssid = STR(WIFI_SSID);
const char *wifi_pwd = STR(WIFI_PWD);

// server setup
AsyncWebServer server(80);
AsyncEventSource events("/events");

// global variables for webpage
float temperature;
float pressure;
float humidity;
float gas_resistance;
float altitude;
char aqi;
float pm_1;
float pm_2;
float pm_10;

// 404 response
void notFound(AsyncWebServerRequest *request)
{
  request->send(404, "text/plain", "Not found");
}

// processor for the HTML response - handles the update in variables
String processor(const String &var)
{
  if (var == "temperature")
  {
    return String(temperature);
  }
  else if (var == "pressure")
  {
    return String(pressure);
  }
  else if (var == "humidity")
  {
    return String(humidity);
  }
  else if (var == "gas_resistance")
  {
    return String(gas_resistance);
  }
  else if (var == "altitude")
  {
    return String(altitude);
  }
  else if (var == "pm_1")
  {
    return String(pm_1);
  }
  else if (var == "pm_2")
  {
    return String(pm_2);
  }
  else if (var == "pm_10")
  {
    return String(pm_10);
  }
  else
    return String("Error");
}

// main HTML
const char index_html[] PROGMEM = R"rawliteral(<!DOCTYPE HTML><html><body>
<h2>Temperature: <span id="temp">%temperature%</span>&deg;C</h2>
<h2>Pressure: <span id="press">%pressure%</span>hPa</h2>
<h2>Humidity: <span id="hum">%humidity%</span>&percnt;</h2>
<h2>Gas Resistance: <span id="gas">%gas_resistance%</span>&K&ohm;</h2>
<h2>Altitude: <span id="alti">%altitude%</span>m</h2>
<h2>PM 1.0: <span id="pm_1">%pm_1%</span>[ug/m3]</h2>
<h2>PM 2.5: <span id="pm_2">%pm_2%</span>[ug/m3]</h2>
<h2>PM 10: <span id="pm_10">%pm_10%</span>[ug/m3]</h2>
</body>
<script>
if (!!window.EventSource) {
 var source = new EventSource('/events');
 
 source.addEventListener('open', function(e) {
  console.log("Events Connected");
 }, false);
 source.addEventListener('error', function(e) {
  if (e.target.readyState != EventSource.OPEN) {
    console.log("Events Disconnected");
  }
 }, false);
 
 source.addEventListener('temperature', function(e) {
  console.log("temperature", e.data);
  document.getElementById("temp").innerHTML = e.data;
 }, false);

 source.addEventListener('pressure', function(e) {
  console.log("pressure", e.data);
  document.getElementById("press").innerHTML = e.data;
 }, false);

 source.addEventListener('humidity', function(e) {
  console.log("humidity", e.data);
  document.getElementById("hum").innerHTML = e.data;
 }, false);

 source.addEventListener('gas_resistance', function(e) {
  console.log("gas_resistance", e.data);
  document.getElementById("gas").innerHTML = e.data;
 }, false);

 source.addEventListener('altitude', function(e) {
  console.log("altitude", e.data);
  document.getElementById("alti").innerHTML = e.data;
 }, false);

 source.addEventListener('pm_1', function(e) {
  console.log("pm_1", e.data);
  document.getElementById("pm_1").innerHTML = e.data;
 }, false);

 source.addEventListener('pm_2', function(e) {
  console.log("pm_2", e.data);
  document.getElementById("pm_2").innerHTML = e.data;
 }, false);

 source.addEventListener('pm_10', function(e) {
  console.log("pm_10", e.data);
  document.getElementById("pm_10").innerHTML = e.data;
 }, false);
}
</script>

</html>)rawliteral";

void setup()
{
  Serial.begin(115200);
  // Serial.begin(9600);
  while (!Serial)
    ;
  Serial.println(F("BME680 async test"));

  if (!bme.begin())
  {
    Serial.println(F("Could not find a valid BME680 sensor, check wiring!"));
    while (1)
      ;
  }
  pms.init();

  delay(1000);
  // Set the device as a Station and Soft Access Point simultaneously
  WiFi.mode(WIFI_STA);
  Serial.println("wifi_ssid: ");
  Serial.println(wifi_ssid);
  Serial.println("wifi_pwd: ");
  Serial.println(wifi_pwd);
  WiFi.begin(wifi_ssid, wifi_pwd);
  while (WiFi.status() != WL_CONNECTED)
  {
    delay(1000);
    Serial.println("Setting as a Wi-Fi Station..");
  }
  Serial.print("Station IP Address: ");
  Serial.println(WiFi.localIP());
  Serial.println();

  // Define a route to serve the HTML page
  server.on("/", HTTP_GET, [](AsyncWebServerRequest *request)
            {
              Serial.println("ESP32 Web Server: New request received:"); // for debugging
              Serial.println("GET /");                                   // for debugging
              request->send_P(200, "text/html", index_html, processor);
              // request->send(200, "text/plain", "Hello World!");
            });

  // Handle Web Server Events
  events.onConnect([](AsyncEventSourceClient *client)
                   {
    if(client->lastId()){
      Serial.printf("Client reconnected! Last message ID that it got is: %u\n", client->lastId());
    }
    // send event with message "hello!", id current millis
    // and set reconnect delay to 1 second
    client->send("hello!", NULL, millis(), 10000); });

  // server handlers
  server.onNotFound(notFound);
  server.addHandler(&events);
  // Start the server
  server.begin();

  // Set up oversampling and filter initialization
  bme.setTemperatureOversampling(BME680_OS_8X);
  bme.setHumidityOversampling(BME680_OS_2X);
  bme.setPressureOversampling(BME680_OS_4X);
  bme.setIIRFilterSize(BME680_FILTER_SIZE_3);
  bme.setGasHeater(320, 150); // 320*C for 150 ms

  pinMode(LED, OUTPUT);
}

void loop()
{
  Serial.println();
  Serial.println();

  digitalWrite(LED, HIGH);
  Serial.println("LED is on");
  Serial.println();

  Serial.print(F("BME 680 Reading started \n"));

  // Tell BME680 to begin measurement.
  unsigned long endTime = bme.beginReading();
  if (endTime == 0)
  {
    Serial.println(F("Failed to begin reading :("));
    return;
  }

  delay(50);
  if (!bme.endReading())
  {
    Serial.println(F("Failed to complete reading :("));
    return;
  }
  Serial.print(F("Reading completed \n"));

  // Serial.print(F("Temperature = "));
  // Serial.print(bme.temperature);
  // Serial.println(F(" *C"));
  temperature = bme.temperature;
  events.send(String(temperature).c_str(), "temperature", millis());

  // Serial.print(F("Pressure = "));
  // Serial.print(bme.pressure / 100.0);
  // Serial.println(F(" hPa"));
  pressure = bme.pressure / 100.0;
  events.send(String(pressure).c_str(), "pressure", millis());

  // Serial.print(F("Humidity = "));
  // Serial.print(bme.humidity);
  // Serial.println(F(" %"));
  humidity = bme.humidity;
  events.send(String(humidity).c_str(), "humidity", millis());

  // Serial.print(F("Gas = "));
  // Serial.print(bme.gas_resistance / 1000.0);
  // Serial.println(F(" KOhms"));
  gas_resistance = bme.gas_resistance / 1000.0;
  events.send(String(gas_resistance).c_str(), "gas_resistance", millis());

  // Serial.print(F("Approx. Altitude = "));
  // Serial.print(bme.readAltitude(SEALEVELPRESSURE_HPA));
  // Serial.println(F(" m"));
  altitude = bme.readAltitude(SEALEVELPRESSURE_HPA);
  events.send(String(gas_resistance).c_str(), "altitude", millis());

  Serial.print(F("PMS7003 Reading started \n"));
  pms.read(); // read the PM sensor
  // Serial.print(F("PM1.0 "));
  // Serial.print(pms.pm01);
  pm_1 = pms.pm01;
  events.send(String(pm_1).c_str(), "pm_1", millis());
  // Serial.print(F("\n"));
  // Serial.print(F("PM2.5 "));
  // Serial.print(pms.pm25);
  pm_2 = pms.pm25;
  events.send(String(pm_2).c_str(), "pm_2", millis());
  // Serial.print(F("\n"));
  // Serial.print(F("PM10 "));
  // Serial.print(pms.pm10);
  pm_10 = pms.pm10;
  events.send(String(pm_10).c_str(), "pm_10", millis());
  // Serial.println(F(" [ug/m3]"));
  Serial.print(F("PMS7003 Reading completed \n"));

  Serial.println();

  digitalWrite(LED, LOW);
  Serial.println("LED is off");
  delay(60000); // wait for 60 seconds
}

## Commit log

2024-03-22 updated guide pending expansion board
2024-03-22 completed before adding PMS7003
    [case.stl, lid.stl]
2024-03-22 added lid v2
    [lid_v2.stl]
2024-03-23 edited license and added info on new 3D parts
    [case.stl, case_v2.stl, lid.stl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]
2024-03-23 added additional instructions on assembly
2024-03-23 added instructions for esp32 and future improvements and images
2024-03-24 added a comment on case design
2024-03-29 finalised pms7003 integration
    [case_soldered.stl]
